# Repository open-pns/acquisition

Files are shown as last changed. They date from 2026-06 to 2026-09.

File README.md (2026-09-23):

# pns-acquisition
WIP - dual pcb arm band for multi channel semg acquisition

Clamshell design, 8 channels, modular design with DB and MB

Status:

Current plan is to finish design of DB, get boards manufactured, and test with nrf5340 devboard. After testing confirms functionality, design a pcb to stack with the DB to move SoC functionality, IMU, and power to the wrist.
HW:
- DB : schematic complete, layout underway
- MB : schematic v1 complete, in need of revision
# Hardware
---
## Current Layout



DB PCB Progress (9-10-26) - see [docs/db/daughterboard-adr.md](./docs/db/daughterboard-adr.md) for more details.
- first pass ground pour (not final)
- need to confirm power rail is within spec (max current is 1.2A)
- Need to better organize silkscreen lettering

## Previous Versions


# Firmware
---
Barebones layout gets finalized.
- devboard: flashing + building works, no progress on actual functionality
- final PCB: n/a

## License
Firmware (`fw/`) — MIT  
Hardware (`hw/`) — CERN-OHL-P v2  
Documentation (`docs/`) — CC BY 4.0

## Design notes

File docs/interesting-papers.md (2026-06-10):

HD-EMG Electrode Count and Feature Selection Influence on Pattern-based Movement Classification Accuracy
https://ieeexplore.ieee.org/document/9175210

Evaluation of Hand Action Classification Performance Using Machine Learning Based on Signals from Two sEMG Electrodes
https://pmc.ncbi.nlm.nih.gov/articles/PMC11054923/

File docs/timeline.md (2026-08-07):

## Current Status
 
| Item | Status |
|---|---|
| Daughter board schematic | Complete |
| Main board schematic | ~75% -- est. complete Jul 24 |
| Layout | Not started |
| Gerbers | Not submitted |
| Firmware | Not started |
| Prototype validation | Not started |
 
---
 
## Timeline
 
### Schematic
 
| Date | Milestone |
|---|---|
| Jun 26 | **Daughter board schematic complete** |
| Jul 24 | **Main board schematic complete** |
| Jul 25 | **Schematic review & ERC clean** |
 
---
 
### Layout
 
| Date | Milestone |
|---|---|
| Jul 26 | **Layout begins** |
| Jul 26–Aug 7 | **Daughter board layout complete** |
| Aug 1–Aug 11 | **Main board layout complete** |
| Aug 12 | **Gerbers submitted + BOM ordered** |
 
---
 
### Prototype Validation (parallel to layout)
 
| Date | Milestone |
|---|---|
| Jul 26 | **Prototype kit ordered** |
| Aug 25 | **Firmware scaffolding complete** |
| Aug 30 | **BMI270 prototype validation** |
 
---
 
### Fabrication & Bring-Up
 
| Date | Milestone |
|---|---|
| Aug 30 | **PCBs arrive** |
| Sep 4 | **On device firmware** |
| Sep 15 | **Streaming pipeline complete** |
| Sep 15–22 | **Polish & documentation** |
| Sep 22 | **Presentation target** |

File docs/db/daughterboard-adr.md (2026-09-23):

## TODO:

---

- update DRL PIN / add a dip switch to change between DGND (disabled) and a feedback circuit
- Update filter and Ccm Caps based on datasheets criteria
- ADD Power Down functionality to the ads1298 for power saving functionality.
- Replace C2 with a more hand solderable cap
- ground pour

## 9-22-2026 - ew
- first pass ground pour



## 9-10-2026 -ew

- Completed first pass of 2nd revision - barring poly pour for ground. Layout is much more spread out to (hopefully) help with separation for the analog signals.


## 8-22-2026 -ew

- Received [medical instrumentation application and design 4th edition](https://www.amazon.com/Medical-Instrumentation-Application-John-Webster/dp/0471676004)
- Received [Domed snap electrodes with Ag/AgCl coating](https://datwyler.com/company/innovation/softpulse/products/) from Datwyler (Thank you Datwyler for sending these over!!)

## 8-19-2026 -ew

Some thoughts on the current state of the board


1. Biosignal lines running under the IC are hard stop problems. These should be considered non functional in their current state
2. Rerouting the signal lines out from under the IC is difficult. They could be routed around the top, but the signal lines get long, which is bad due to EMF concerns
3. This IC's pin locations are clearly not optimized for a middle of the board application. Ideal application is something like:
   [electrodes] -> [IC] -> data connect
4. Analog lines on the right side of the board need better isolation from data lines. ""
5. board is 6 cm x 3 cm. Expansion to ~6 cm x 5 cm could solve a lot of these problems by giving the IC some breathing room. Layout might look silly though


I generally like A, digital lines could get messy but I would rather deal with messy digital lines than messy biosignal lines. I am not sure about B -- B.1 gets pretty long. I worry that those high impedance lines could act as antennas.

I have ordered [Medical Instrumentation: Application and Design 4e](https://a.co/d/0hpU3cl9) for further research on best practices for carrying biosignals

## 8-18-2026 -ew

Updated DB AFE to include LPF with differential cap, and added common mode cap.

From ADS1298 datasheet:



Diff cap (LPF) calculated with a cutoff of 1.7 kHz to be 4.7 nF with a 10kohm resistor
Common mode cap (Ccm) was made ~10x smaller - 270 pF.

Note that these were not chosen to adhere to image 2's highlighted criteria. I should go back and check/update the specific cap type before ordering

## 7-22-2026 -ew

Recieved devboard and breakout for IMU

## 7-20-26 -ew

initilized PCB file - missing footprint to adc

## 6-30-26 -ew

- Added 14 pin FFC header to daughterboard schematic (Molex 52793-1470 — 14 pos, 1.0mm pitch, Right Angle). arranged pins so pin 1 & 14 are gnd to protect against open loop problems while connecting[...]
- Switched from ports to netlabels for main schematic net
  Wired inputs/outputs from FFC header as follows:

---

| Signal | Net Name | Direction |
| --- | --- | --- |
| SPI clock | SCLK_AFE | MCU → ADS1298 |
| SPI data in (to ADS1298) | MOSI_AFE | MCU → ADS1298 |
| SPI data out (from ADS1298) | MISO_AFE | ADS1298 → MCU |
| Chip select (active low) | ~CS_AFE | MCU → ADS1298 |
| Data ready interrupt (active low) | ~DRDY_AFE  | ADS1298 → MCU |
| Reset (active low) | ~RESET_AFE | MCU → ADS1298 |
| Start conversion | START_AFE  | MCU → ADS1298 |

---

| Signal | Pin Name | TQFP64 Pin # |
| --- | --- | --- |
| ~CS_AFE | \*CS | 39 |
| ~DRDY_AFE  | \*DRDY | 47 |
| ~RESET_AFE | \*RESET  | 36 |
| START_AFE  | START | 38 |
| SCLK_AFE | SCLK | 40 |
| MOSI_AFE | DIN | 31 |
| MISO_AFE | DOUT | 43 |

---

## 6-24-26 -ew

updaing pins:
Pin |Update
--|--
VCAP1 |22µF cap to AVSS — required
VCAP2 |1µF cap to AVSS — required
VCAP3 |1µF cap to AVSS — required
VCAP4 |1µF cap to AVSS — required
CLKSEL |Tie high (DVDD) for internal oscillator, or low for external clockDAISY_INTie to DGND if not using daisy chain
RESV1 |Must tie to DGND per datasheet
PWDN |Active low — tie high to DVDD through resistor, or control from MCU
RESET |Active low — pull high, control from MCU via the cable connector
START |Control from MCU via cable connector
RESP_MODP/N |Leave floating — these are ADS129xR only, not needed on ADS1298
GPIO1- |4Tie to DGND if unused

setting clocksel high for now. may need to change to sync multiple adcs

further considerations:

after deciding to include and ADC on the mother board to make biosignal transmission more reliable, look into AFE159RP4. Might be lower power with 4 channels. newer chip.
https://www.ti.com/product/AFE159RP4

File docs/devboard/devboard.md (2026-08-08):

DK connector interface
https://docs.nordicsemi.com/r/bundle/ug_nrf5340_dk/page/ug/dk/connector_if.html

BMI270 spec sheet
https://github.com/sparkfun/SparkFun_Qwiic_6DoF_BMI270/blob/main/Documents/BMI270-Datasheet.pdf
https://cdn.sparkfun.com/assets/5/c/0/0/d/bst-bmi270-ds000.pdf

BMI270 schematic
https://cdn.sparkfun.com/assets/c/a/3/d/f/SparkFun_Qwiic_6DoF_BMI270-Schematic.pdf

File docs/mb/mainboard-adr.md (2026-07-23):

7-9-2026
reference schematics : https://docs.nordicsemi.com/r/bundle/ps_nrf5340/page/chapters/ref_circuitry.html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

choosing to go with QKAA option 1 for built in VDD voltage regulation (better for connection to single cell lipo)

7-19-26

added IMU & completed basic wiring

TODO:
- power
- IMU

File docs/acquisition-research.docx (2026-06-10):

PNS ACQUISITION PLATFORM

Research Document

Elliot Wyrick

Computer Engineering – Purdue University

May 2026 – Rev 0.1 – Research Draft

# 1 Purpose & Project Scope

This document captures the formal design research for a wrist or arm worn surface EMG (sEMG) wearable. It covers the first three phases of the V-Model development process: Requirement Gathering, System Analysis, and Architecture Design. This wearable will form the basis for future experiments and projects whose scopes may not be included in this document.

## 1.1 Goals

- Build a multi-channel dry electrode platform for capturing sEMG data, worn at the wrist / forearm.
- Stream captured sEMG and IMU data over USB or Bluetooth to a host PC or mobile device for storage and processing.

## 1.2 Future-Looking Goals (Out of Scope)

- On-device ML gesture classification — deferred until data acquisition is verified and validated.
- Gel electrode compatibility — current scope is restricted to dry electrodes.
- Battery charging / integration — ideally fully wireless, but the complexity of a charging circuit is not critical to this project.

# 2 System Requirements

All requirements are stated as measurable, testable criteria. Priority levels follow MoSCoW (Must-have, Should-have, Could-have, Won't-have).

ID | Requirement | Rationale | Target / Limit | Priority
SIG-01 | ADC resolution ≥ 24 bit | Raw sEMG signals are in the µV range, amplified to mV. A 24-bit ADC with a 5V reference yields an LSB of ~300 nV, well below the µV-level signals of interest. | 24-bit minimum | MUST
SIG-02 | Sampling rate ≥ 2 kSPS per channel | sEMG spectral content spans ~50–500 Hz for gross gestures. Nyquist requires ≥ 1 kSPS; 2 kSPS provides the necessary anti-alias margin. Target 2000 SPS aligns with the ADS1298's valid data rates. | Target 2000 SPS | MUST
SIG-03 | Channel count ≥ 8 differential | 8 bipolar channels provide sufficient spatial coverage for wrist-level gesture discrimination and robustness as a generalized acquisition platform. Each channel is a differential pair across a muscle belly. | 8 channels minimum | MUST
SIG-04 | Input-referred noise ≤ 1 µVrms | Motor unit action potential amplitude at the skin surface can be <10 µV [2]. The noise floor must sit well below this. | ≤ 1 µVrms | MUST
SIG-05 | CMRR ≥ 80 dB at 50/60 Hz | Powerline interference at 50/60 Hz is the dominant noise source with dry electrodes. High CMRR suppresses it at the AFE before digital filtering. | ≥ 80 dB | MUST
SIG-06 | Input impedance ≥ 500 MΩ differential | Dry electrode-skin impedance can reach megaohms. AFE input impedance must be >> electrode impedance to avoid signal attenuation and CMRR degradation. | ≥ 500 MΩ | MUST
CON-01 | BLE 5.x wireless data stream to host | Wired tether limits wearability and introduces motion artifacts via cable pull. BLE 5.x provides sufficient throughput for compressed sEMG at target sample rates. | BLE 5.0 or later | COULD
CON-02 | BLE throughput ≥ 384 kbps effective | 8 ch × 2000 SPS × 24 bit = 384 kbps raw uncompressed. BLE 5.x 2M PHY provides up to ~2 Mbps at the PHY layer; effective application-layer throughput comfortably exceeds 384 kbps after protocol overhead. | ≥ 384 kbps sustained | COULD
CON-03 | SWD debug port accessible on main board | Required for firmware flashing and live debugging. | 10-pin SWD header | MUST
CON-04 | USB data streaming to host | USB provides a reliable, wired data path for bench sessions and initial validation independent of BLE. The nRF5340 supports USB device mode natively. Required regardless of whether BLE is also implemented. | USB Full Speed (12 Mbps) — nRF5340 native capability; provides ~31× headroom over the 384 kbps raw data rate | MUST
IMU-01 | 6-DoF IMU minimum (accel + gyro) | Wrist rotation and forearm orientation are covariates for gesture disambiguation. | 6-DoF; 9-DoF preferred | MUST
IMU-02 | IMU ODR ≥ 200 Hz | Intentional wrist gestures have a fundamental frequency of ~3–5 Hz with harmonics up to ~30 Hz. Nyquist requires ≥ 60 Hz; 200 Hz provides adequate margin and is sufficient for time-domain sensor fusion with sEMG data. | ≥ 200 Hz | SHOULD
PWR-01 | Battery life ≥ 4 hours continuous acquisition | Minimum useful session length for research data collection. | ≥ 4 hours at full operation | COULD
PWR-02 | System power draw ≤ 50 mW in acquisition mode | Drives battery sizing. As a reference: a 200 mAh LiPo (3.7 V, 740 mWh) at 50 mW yields ~14 hours theoretical — actual capacity to be confirmed during PCB design. | ≤ 50 mW target | COULD
FORM-01 | Wrist/forearm wearable form factor | Target muscle groups require placement between wrist and elbow. | Forearm band, ≤ 40 mm width | MUST
FORM-02 | Main/daughter board split architecture | Main board houses the AFE, MCU, IMU, and power management. Daughterboard handles electrode connector placement and routes all electrode signals back to the main board. No secondary AFE is anticipated. | Board-to-board connector | MUST

# 3 System Architecture

## 3.1 Block Diagram

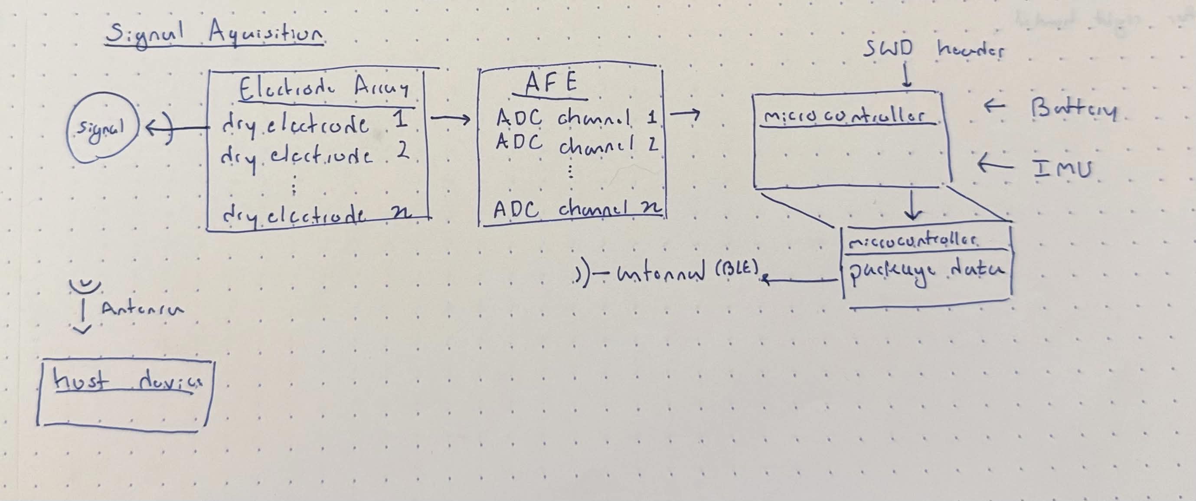
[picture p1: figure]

## 3.2 Block Descriptions

Block | Function
Electrode Array | 8 dry electrode pairs (8 differential channels per SIG-03)
Analog Front End (AFE) | 8-channel ADC & instrumentation amplifier
MCU / Radio | Microcontroller + BLE SoC
IMU | 6/9 DoF inertial measurement unit
Power Management | LiPo + PMIC – or wall power
Host Interface | USB (wired, MUST) and BLE (wireless, COULD) — PC / Mobile

## 3.3 Power Architecture

Ideally, the band will be battery powered. The legitimacy of this will be determined during modeling and PCB design.

# 4 Hardware Stack Evaluation

Three candidates are evaluated across the AFE, MCU, and IMU. Each component class is first evaluated independently, then the stacks are established and compared. The goal is to arrive at a stack that balances cost, flexibility, and accuracy.

## 4.1 Analog Front End (AFE)

The AFE is the most critical selection. Requirements SIG-01 through SIG-06 tightly constrain the field. Only dedicated biopotential ADCs satisfy the channel count, noise floor, and input impedance requirements simultaneously.

Part | Channels | Max SPS | Noise | CMRR | Zin | Bus | Notes
ADS1298 (TI) ~$51 | 8 ch / 24-bit | 32 kSPS/ch | 4 µVpp typ | 115 dB typ | 1 GΩ diff | SPI | Medical ECG-grade biopotential AFE; well-documented for sEMG/ECG/EEG; DRDY per chip
ADS1299 (TI) ~$86 | 8 ch / 24-bit | 16 kSPS/ch | 1 µVpp typ | 110 dB typ | 1 GΩ diff | SPI | EEG-optimized, lower noise floor; higher cost; overkill for sEMG but excellent margin
MAX86150 (Maxim/ADI) | 2 ch / 19-bit | 400 SPS | ~5 µVrms | ~70 dB | N/A | I2C | PPG+ECG combo IC; insufficient channels and sample rate for multichannel sEMG

ADS1298 vs ADS1299: The ADS1299 offers meaningfully lower noise (1 µVpp vs 4 µVpp). Both parts specify CMRR above 110 dB and far exceed the SIG-05 requirement of 80 dB minimum. For sEMG, both are within spec — sEMG does not require EEG-grade noise floors. The ADS1298's 4 µVpp noise is specified at G=6 and 150 Hz bandwidth; at G=12 and 2000 SPS in low-power mode, the datasheet reports exactly 1.0 µVrms — meeting SIG-04 at the boundary. High-resolution mode at the same conditions yields 1.2 µVrms, which does not meet SIG-04. Low-power mode at G=12 must therefore be the operating configuration to satisfy the noise requirement [3].

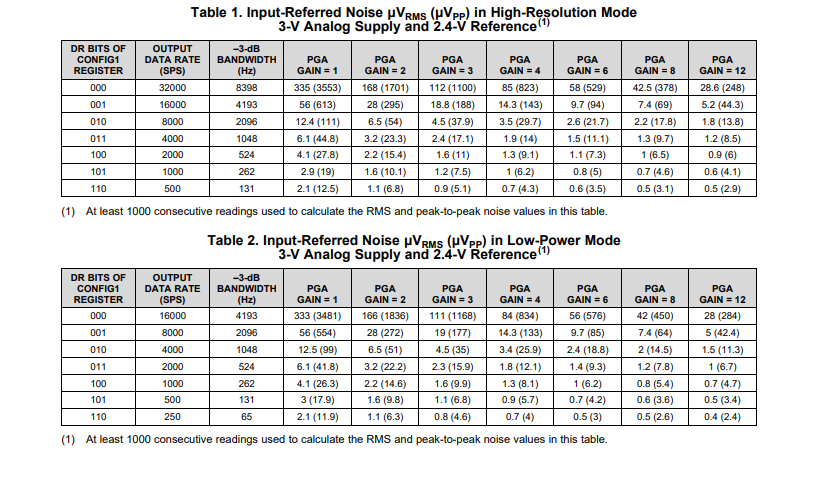
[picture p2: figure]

The ADS1298 is preferred for Stack A due to lower cost, identical SPI interface to the ADS1299, and well-established use in medical-grade biopotential acquisition.

## 4.2 MCU / Radio

The MCU must handle SPI data acquisition from the AFE, I2C from the IMU, BLE streaming, and have sufficient RAM to buffer several acquisition windows without dropping samples. Dual-core architecture is preferred to isolate the radio stack (net core) from application logic.

Part | Core | Flash+RAM | Radio | Dual Core? | Power | SDK | USB | Notes
nRF5340 (Nordic) ~$9 | Dual ARM M33 (128/64 MHz) | App: 1 MB Flash / 512 KB RAM Net: 256 KB Flash / 64 KB RAM | BLE 5.3 + BT Audio | Yes (net core) | 3.3 V / ~5 mA idle | ZephyrOS / nRF SDK | FS 12 Mbps device | Industry-standard BLE SoC; dual-core allows DSP isolation; high RAM for streaming buffer; widely used in wearables
nRF52840 (Nordic) ~$7 | Single ARM M4F (64 MHz) | 1 MB + 256 KB | BLE 5.0 | No (single core) | 3.3 V / ~4 mA idle | ZephyrOS / nRF SDK | FS 12 Mbps device | Proven single-core option; no net core separation; adequate but less headroom for on-device ML later
STM32WB55 (ST) ~$8 | Dual ARM M4/M0+ (64/32 MHz) | 1 MB + 256 KB | BLE 5.0 + Zigbee | Yes (M0+ radio) | 3.3 V / ~3 mA idle | STM32CubeWB | FS 12 Mbps device, crystal-less | Competitive dual-core; ST ecosystem; less community support for wearable BLE vs Nordic; good alternative
ESP32-S3 (Espressif) ~$2 | Dual Xtensa LX7 (240 MHz) | 8 MB (ext) | WiFi + BLE 5.0 | Partial | 3.3 V / ~20 mA idle | ESP-IDF | FS OTG (device + host); shared PHY with JTAG — external PHY needed for concurrent use | High compute; WiFi is excess for this application; higher idle power; larger package; less suited to ultra-low-power wearable

The nRF5340 dual-core architecture is a significant advantage: the network core runs the BLE stack autonomously while the application core handles SPI, DMA, and signal processing. This separation should reduce jitter in the data stream and leaves the application core free for future on-device inference.

## 4.3 IMU

The IMU selection is less critical than the AFE, but ODR, power draw, and I2C/SPI compatibility all matter. The IMU runs on the same power budget as the rest of the system and its ODR must be sufficient for the intended motion capture without dominating system power consumption.

Part | DoF | Max ODR | Noise | Bus | Power | Features | Notes
BMI270 (Bosch) ~$4 | 6-DoF (A+G) | 1600 Hz accel / 6400 Hz gyro | 160 µg/√Hz accel | I2C/SPI | ~685 µA @ full ODR (A+G) | Context recognition engine | Ultra-low power, built-in gesture detection, widely used in wearables
LSM6DSV (ST) ~$4 | 6-DoF (A+G) | 7680 Hz | 60 µg/√Hz accel | I2C/SPI | ~650 µA combo high-perf | Smart FIFO + sensor fusion | Onboard sensor fusion engine; ISPU programmable core; slightly higher power; excellent for fusion pipeline
ICM-42688-P (TDK) ~$5 | 6-DoF (A+G) | 32 kHz | 70 µg/√Hz accel | I2C/SPI | ~880 µA low-noise mode | APEX motion processing | Highest ODR of the group; widely used in precision wearables; good supply availability
BNO085 (CEVA/Bosch) ~$13 | 9-DoF + fusion | 400 Hz (fusion out) | N/A (fusion only) | I2C/SPI/UART | ~1.2 mA active | Full AHRS onboard | Outputs quaternions directly; lower raw ODR; higher power; useful if quaternion output is required without fusion code

The BMI270 is selected for Stack A primarily on power budget and wearable ecosystem track record. At the target operating ODR of 400 Hz, the BMI270 draws well below its full-ODR figure of ~685 µA — normal-mode current scales with ODR, and at 400 Hz both axes run comfortably under 500 µA. In low-power and accel-only modes it drops significantly lower, making it the most flexible option for duty-cycling. The LSM6DSV (~650 µA) and ICM-42688-P (~880 µA) figures are at their respective maximum ODR conditions. Its built-in context recognition engine could also be leveraged later for activity-aware calibration. The ICM-42688-P is the better choice if high-rate motion data is needed for fusion (Stack B).

## 4.4 Stack Comparison Summary

Stack | AFE | MCU | IMU | Cost | Signal | Power | Docs | Notes
Stack A (Primary) ~ $64.60 | ADS1298 | nRF5340 | BMI270 | ✓ Best | ✓ Best | ✓ Best* | ✓ Best | All parts well-documented; largest community. *BMI270 power advantage is primarily in low-power and accel-only modes; full A+G ODR draw is comparable to LSM6DSV.
Stack B (High Fidelity) ~ $100.37 | ADS1299 | nRF5340 | ICM-42688-P | ~ OK | ✓✓ Best | ~ OK | ~ OK | Lower noise AFE; best IMU ODR; higher cost; justified only if sub-µV noise is required
Stack C (Budget) ~ $61.23 | ADS1298 | nRF52840 | LSM6DSV | ~ OK | ✓ Best | ~ OK | ✓ Best | Proven single-core MCU; lower BLE throughput ceiling; adequate for 2 kSPS but no dual-core margin

# 5 Selected Stack

## 5.1 Decision: Stack A

Stack A is selected: ADS1298 + nRF5340 + BMI270.

### ADS1298 — AFE

- Meets all signal requirements (SIG-01 through SIG-06) with margin.
- 8 simultaneous differential channels, 24-bit, 32 kSPS max, 115 dB CMRR typical (exceeds SIG-05 requirement of 80 dB minimum).
- Identical SPI interface to ADS1299; if noise floor proves insufficient after benching dry electrodes, the ADS1299 is a drop-in firmware replacement with minor schematic changes.
- Risk: dry electrode impedance mismatch will degrade effective CMRR. Mitigation: implement DRL circuit per ADS1298 datasheet; guard rings on daughterboard traces. DRL location to be determined through experimentation.

### nRF5340 — MCU / Radio

- Dual ARM Cortex-M33 (128 MHz app core / 64 MHz net core) satisfies both processing and radio isolation requirements.
- BLE 5.3 with 2M PHY; effective throughput sufficient for 8 ch × 2000 SPS with packing.
- Large RAM (app core: 512 KB, net core: 64 KB) provides adequate DMA buffer depth to tolerate BLE scheduling gaps.
- ZephyrOS support mature; nRF Connect SDK well-documented for SPI + BLE concurrent operation.
- Risk: nRF5340 requires two firmware images (app core + net core), adding build system complexity. Mitigation: use nRF Connect SDK which handles multi-image builds natively.

### BMI270 — IMU

- 6-DoF, target operating ODR 400 Hz (divides cleanly into 2000 SPS sEMG rate at 5:1); at 400 Hz both axes draw comfortably under 500 µA, well within power budget.
- SPI-compatible; can share SPI bus with ADS1298 via separate CS.
- Risk: 6-DoF lacks magnetometer for absolute heading. If absolute orientation is required in a later revision, upgrade path is BNO085 or a standalone magnetometer.

# References

[1] L. McManus, G. De Vito, and M. M. Lowery, "Analysis and biophysics of surface EMG for physiotherapists and kinesiologists: Toward a common language with rehabilitation engineers," Frontiers in Neurology, vol. 11, p. 576729, 2020, doi: 10.3389/fneur.2020.576729.

[2] C. J. De Luca, "Surface electromyography: Detection and recording," Delsys Incorporated, Technical Tutorial, 2002.

[3] Texas Instruments, "ADS129x low-power, 8-channel, 24-bit analog front-end for biopotential measurements," Datasheet SBAS459, revised 2015.

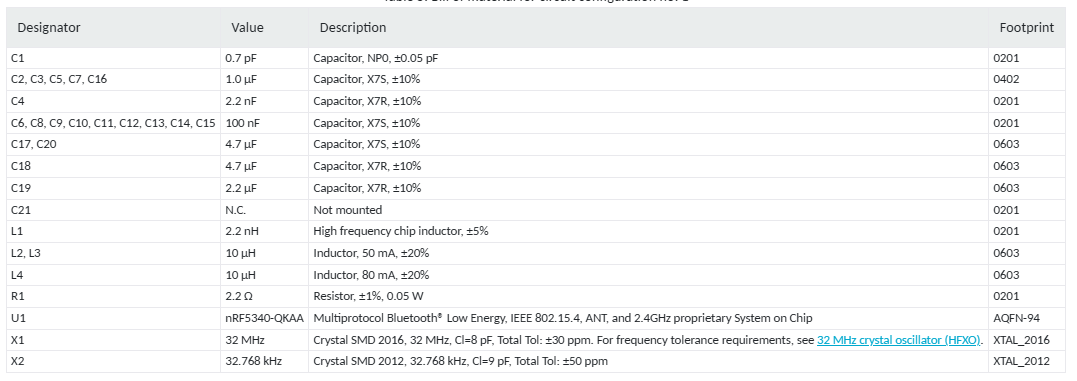
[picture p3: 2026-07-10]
docs/mb/mainboard-adr-img/Screenshot 2026-07-09 230652.png

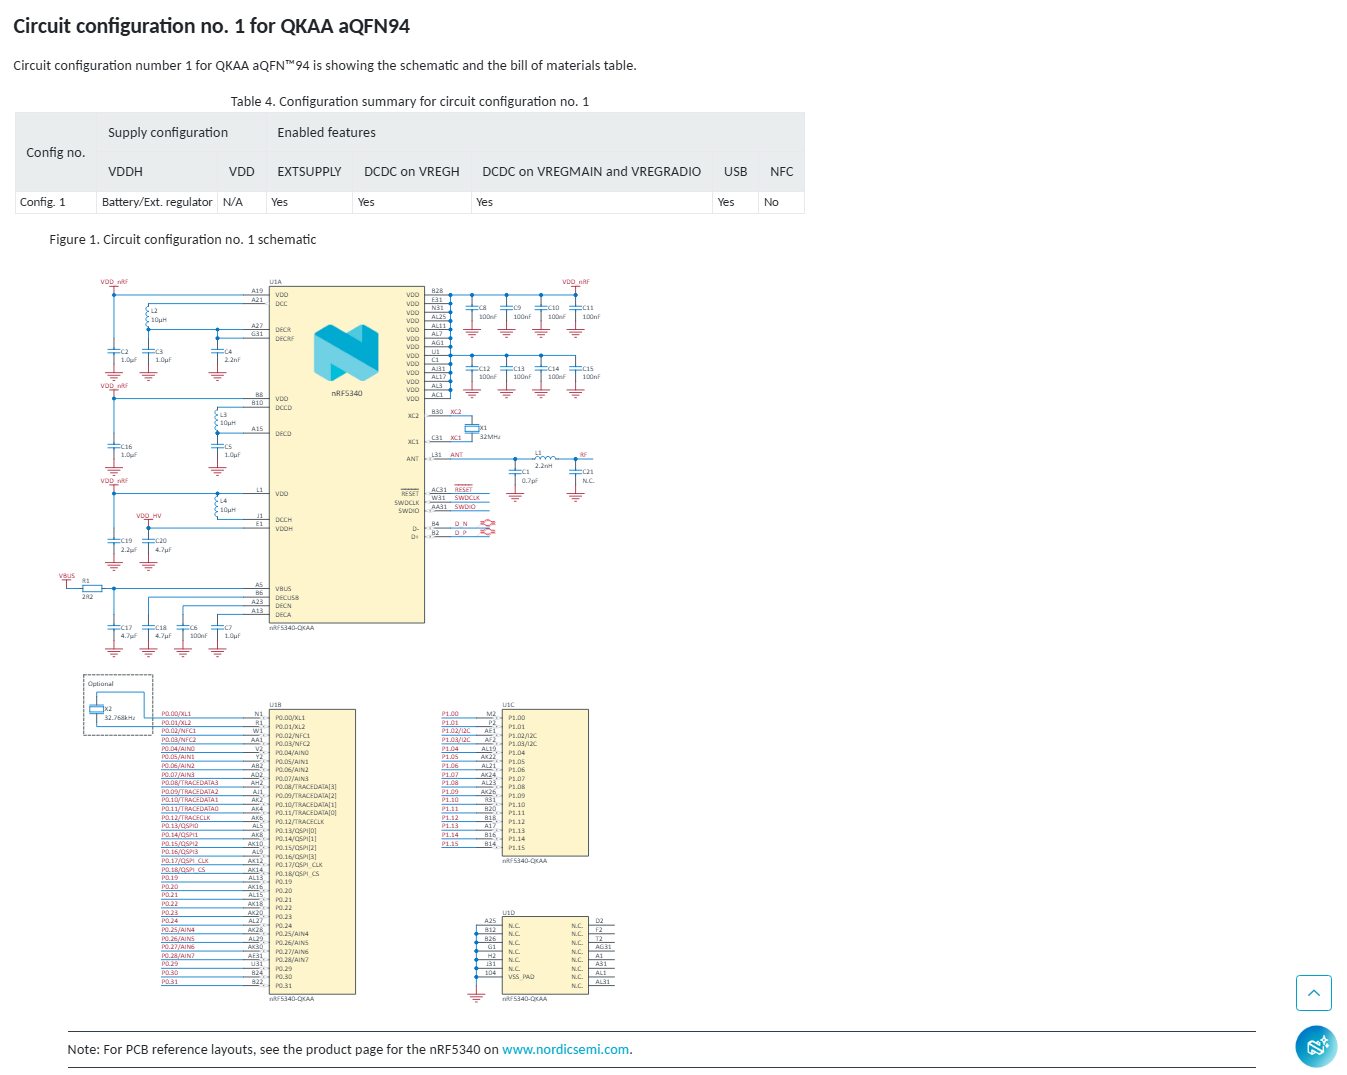
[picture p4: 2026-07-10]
docs/mb/mainboard-adr-img/Screenshot 2026-07-09 230606.png

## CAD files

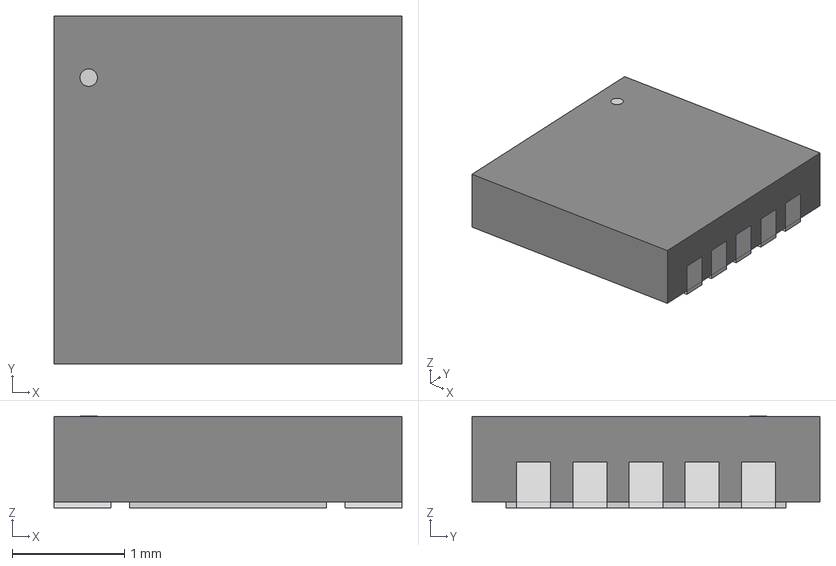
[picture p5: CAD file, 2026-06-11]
hw/3d/DFN-10_DD_LIT.step
3.10 x 3.10 x 0.815 mm

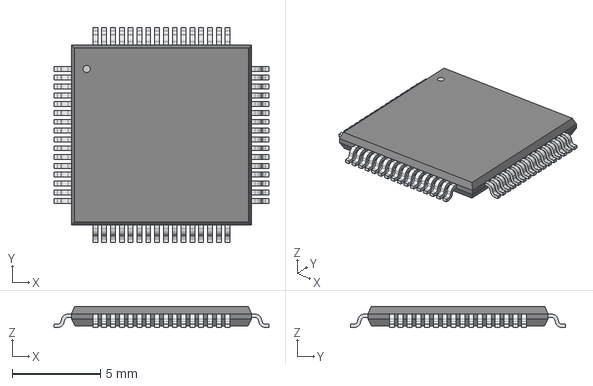
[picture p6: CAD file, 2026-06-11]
hw/3d/PAG64.step
12.2 x 12.2 x 1.20 mm

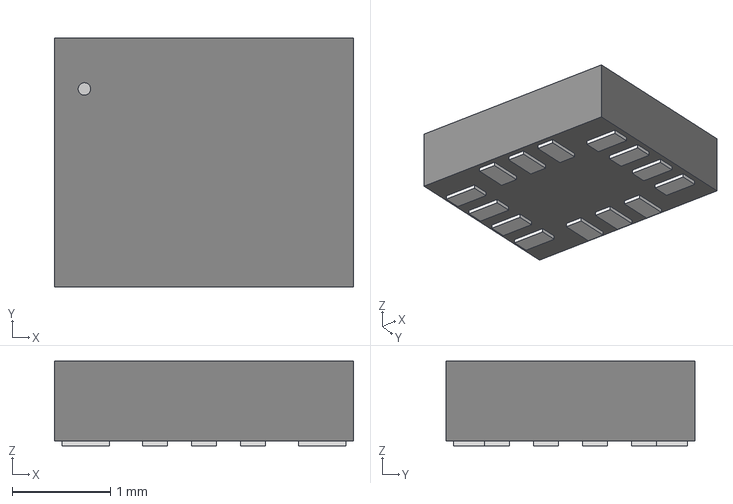
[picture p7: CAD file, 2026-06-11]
hw/3d/BMI270_BOS.step
3.05 x 2.54 x 0.866 mm

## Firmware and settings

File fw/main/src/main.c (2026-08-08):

#include <zephyr/kernel.h>
#include <zephyr/device.h>
#include <zephyr/drivers/i2c.h>
#include <zephyr/sys/printk.h>

#define I2C_NODE            DT_NODELABEL(i2c1)
#define BMI270_I2C_ADDR     0x68   /* default addr, SDO pulled low */
#define BMI270_REG_CHIP_ID  0x00
#define BMI270_CHIP_ID_VAL  0x24

int main(void)
{
    const struct device *i2c_dev = DEVICE_DT_GET(I2C_NODE);

    while (1) {
        printk("--- probing BMI270 ---\n");

        if (!device_is_ready(i2c_dev)) {
            printk("I2C bus not ready\n");
        } else {
            uint8_t chip_id = 0;
            int ret = i2c_reg_read_byte(i2c_dev, BMI270_I2C_ADDR,
                                         BMI270_REG_CHIP_ID, &chip_id);

            if (ret) {
                printk("I2C read failed: %d (check wiring/address)\n", ret);
            } else {
                printk("BMI270 chip ID = 0x%02X (expected 0x%02X)\n",
                       chip_id, BMI270_CHIP_ID_VAL);
            }
        }

        k_msleep(1000);
    }

    return 0;
}

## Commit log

2026-06-11 Add hardware design files and libraries. Altium init.
    Import initial hardware assets for the project: Altium projects (mainboard, daughterboard), component libraries (SchLib/PcbLib/IntLib), reference project configs, 3D STEP models, previews and history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
    [BMI270_BOS.step, DFN-10_DD_LIT.step, PAG64.step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]
2026-06-13 Introduce input protection schematic & update gitignore
    Introduces input protection schematic to consolidate series resisters and clamping diodes. Also updates the gitignore because it was not preventing history documents from being included.
    [daughterboard.SchDoc, input_protection.SchDoc]
2026-06-23 minor change
    [daughterboard.PrjPcb, daughterboard.SchDoc, mainboard.PrjPcb]
2026-06-25 wire up some pins on ads. add adr for daughterboard
    [daughterboard.SchDoc]
2026-07-01 update gitignore & add FFC header to daughterboard
    [daughterboard.SchDoc, input_protection.SchDoc]
2026-07-01 Update daughterboard ADR and schematic - convert to netlabels & tie to pins on ADC
    Reformat daughterboard ADR: convert pin notes into a table and add entry for 6-30-26 documenting a 14-pin 1.0mm FFC header (Molex 52793-1470) and wiring. Record netlabel/port changes, CLKSEL decision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
    [daughterboard.SchDoc]
2026-07-10 wire up nrf5340 propperly to ADS. Major netlabel cleanup for mainboard ADS.
    [daughterboard.PrjPcb, daughterboard.SchDoc, input_protection.SchDoc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]
2026-07-18 Update DB netabels. tie AGNDs, DGNDs, AVDD, DVDD together btw mb & daughterboard
    [daughterboard.SchDoc, mainboard.SchDoc]
2026-07-21 wire up and integrate BMI270
    [mainboard.SchDoc]
2026-07-21 init db pcb
    [daughterboard.PcbDoc]
2026-07-23 update adr
    [daughterboard.PrjPcb]
2026-07-25 swap generic components on DB to components with footprints.
    [daughterboard.PcbDoc, daughterboard.SchDoc, input_protection.SchDoc]
2026-07-28 add no ERC directives to floating pins on DB - ERC clean
    [daughterboard.SchDoc, input_protection.SchDoc]
2026-07-31 Update PCB dimensions
    [daughterboard.PcbDoc, daughterboard.PrjPcb]
2026-08-01 jst connector swapped for a smaller version, some updates to pcb
    -add differential pair label to MB
    -smaller jst connector chosen (not connected)
    -polygon pour & test pad demo on DB pcb
    [daughterboard.PcbDoc, daughterboard.PrjPcb, daughterboard.SchDoc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]
2026-08-07 add properly spaced electrode pads & begin layout mockup
    No trace routing yet. I need to find smaller caps, and decide if adding holes for standoffs (to make DB components of MB modular)
    [daughterboard.PcbDoc]
2026-08-08 Init fw for mainboard & BMI270
    Simple "Hello World" on the nrf5349 DK communicating over I2C with the bmi270 breakout board.
2026-08-08 Update 1u capacitors to 1206 (imperial) sized alternatives
    holy space savings
    [daughterboard.PcbDoc, daughterboard.SchDoc]
2026-08-09 1st pass traces & connector nets implemented
    Still much to do:
    - ground hookups and pour
    - DRL circuit
    - R1
    - Read up on proper trace widths and spacing
    [daughterboard.PcbDoc, daughterboard.SchDoc, input_protection.SchDoc]
2026-08-10 Route DRL to IC
    [daughterboard.PcbDoc]
2026-08-12 re route DB_AVDD to come direct from connector instead of through chip
    Removed two vias and re routed. This should reduce current load on IC
    [daughterboard.PcbDoc]
2026-08-12 wire up R1
    [daughterboard.PcbDoc]
2026-08-12 Revise README with current project status and plans
2026-08-13 fix incorrect vias & shrink all vias to 0.3mm hole diameter/0.6mm pad diameter
    [daughterboard.PcbDoc]
2026-08-19 Update AFE with LPF & diff cap
    [daughterboard.PcbDoc, daughterboard.SchDoc, input_protection.SchDoc]
2026-08-19 Add updates for DB AFE and capacitor specifications
    Updated daughterboard ADR with new AFE details and capacitor specifications.
2026-08-20 Document current state and thoughts on db
2026-08-24 Begin PCB redesign (type A)
    [daughterboard.PcbDoc, daughterboard.SchDoc, input_protection.SchDoc]
2026-08-24 init mainboard PCB
    [mainboard.PcbDoc]
2026-09-11 update afe caps so ground pads are more easily accessible
    [daughterboard.PcbDoc]
2026-09-11 run power rail and wire up DB_AVDD
    [daughterboard.PcbDoc]
2026-09-11 route DRL and cut board down in size
    [daughterboard.PcbDoc]
2026-09-11 update ADR & wire up jst connector
    [daughterboard.PcbDoc]
2026-09-11 clean up component labels
    [daughterboard.PcbDoc]
2026-09-11 chamfer pcb edges
    [daughterboard.PcbDoc]
2026-09-23 ground pour first pass
    [daughterboard.PcbDoc]
2026-09-23 Revise README for project status and PCB updates
    Updated README with current project status and PCB progress.
